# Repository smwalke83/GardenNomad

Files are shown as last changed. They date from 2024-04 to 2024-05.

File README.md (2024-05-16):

The Garden Nomad is a garden monitoring system that monitors local environmental data - as well as having a deployable digital PH meter - and sends it to the cloud. This project was done for the CNM Ingenuity IoT Bootcamp. It is the capstone project. In this repository you will find all of the documentation for this project. You will see six different folders here:

Code - This contains all of the coding I did for this project. There are several test code files, as well as the final code.

Proposal - Contains the original project proposal.

Drawings, Notes, and Flowcharts - Contains everything that was in my notebook at the end of this project. Conceptual drawings, measurements, notes, flowcharts, etc.

Fritzing - Contains the wiring schematic and breadboard fritzing files.

Garden Nomad PCB - Contains the files for the Printed Curcuit Board design.

Solidworks and Other Design - Contains all the Solidworks files for the 3D printed housing design, as well as an Adobe Illustrator file for the acrylic piece that was cut on the laser cutter.

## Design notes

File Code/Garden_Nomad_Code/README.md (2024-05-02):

# Garden_Nomad_Code

This firmware project was created using [Particle Developer Tools](https://www.particle.io/developer-tools/) and is compatible with all [Particle Devices](https://www.particle.io/devices/).

Feel free to replace this README.md file with your own content, or keep it for reference.

## Table of Contents
- [Introduction](#introduction)
- [Prerequisites To Use This Template](#prerequisites-to-use-this-repository)
- [Getting Started](#getting-started)
- [Particle Firmware At A Glance](#particle-firmware-at-a-glance)
  - [Logging](#logging)
  - [Setup and Loop](#setup-and-loop)
  - [Delays and Timing](#delays-and-timing)
  - [Testing and Debugging](#testing-and-debugging)
  - [GitHub Actions (CI/CD)](#github-actions-cicd)
  - [OTA](#ota)
- [Support and Feedback](#support-and-feedback)
- [Version](#version)

## Introduction

For an in-depth understanding of this project template, please refer to our [documentation](https://docs.particle.io/firmware/best-practices/firmware-template/).

## Prerequisites To Use This Repository

To use this software/firmware on a device, you'll need:

- A [Particle Device](https://www.particle.io/devices/).
- Windows/Mac/Linux for building the software and flashing it to a device.
- [Particle Development Tools](https://docs.particle.io/getting-started/developer-tools/developer-tools/) installed and set up on your computer.
- Optionally, a nice cup of tea (and perhaps a biscuit).

## Getting Started

1. While not essential, we recommend running the [device setup process](https://setup.particle.io/) on your Particle device first. This ensures your device's firmware is up-to-date and you have a solid baseline to start from.

2. If you haven't already, open this project in Visual Studio Code (File -> Open Folder). Then [compile and flash](https://docs.particle.io/getting-started/developer-tools/workbench/#cloud-build-and-flash) your device. Ensure your device's USB port is connected to your computer.

3. Verify the device's operation by monitoring its logging output:
    - In Visual Studio Code with the Particle Plugin, open the [command palette](https://docs.particle.io/getting-started/developer-tools/workbench/#particle-commands) and choose "Particle: Serial Monitor".
    - Or, using the Particle CLI, execute:
    ```
    particle serial monitor --follow
    ```

4. Uncomment the code at the bottom of the cpp file in your src directory to publish to the Particle Cloud! Login to console.particle.io to view your devices events in real time.

5. Customize this project! For firmware details, see [Particle firmware](https://docs.particle.io/reference/device-os/api/introduction/getting-started/). For information on the project's directory structure, visit [this link](https://docs.particle.io/firmware/best-practices/firmware-template/#project-overview).

## Particle Firmware At A Glance

### Logging

The firmware includes a [logging library](https://docs.particle.io/reference/device-os/api/logging/logger-class/). You can display messages at different levels and filter them:

```
Log.trace("This is trace message");
Log.info("This is info message");
Log.warn("This is warn message");
Log.error("This is error message");
```

### Setup and Loop

Particle projects originate from the Wiring/Processing framework, which is based on C++. Typically, one-time setup functions are placed in `setup()`, and the main application runs from the `loop()` function.

For advanced scenarios, explore our [threading support](https://docs.particle.io/firmware/software-design/threading-explainer/).

### Delays and Timing

By default, the setup() and loop() functions are blocking whilst they run, meaning that if you put in a delay, your entire application will wait for that delay to finish before anything else can run. 

For techniques that allow you to run multiple tasks in parallel without creating threads, checkout the code example [here](https://docs.particle.io/firmware/best-practices/firmware-template/).

(Note: Although using `delay()` isn't recommended for best practices, it's acceptable for testing.)

### Testing and Debugging

For firmware testing and debugging guidance, check [this documentation](https://docs.particle.io/troubleshooting/guides/build-tools-troubleshooting/debugging-firmware-builds/).

### GitHub Actions (CI/CD)

This project provides a YAML file for GitHub, automating firmware compilation whenever changes are pushed. More details on [Particle GitHub Actions](https://docs.particle.io/firmware/best-practices/github-actions/) are available.

### OTA

To learn how to utilize Particle's OTA service for device updates, consult [this documentation](https://docs.particle.io/getting-started/cloud/ota-updates/).

Test OTA with the 'Particle: Cloud Flash' command in Visual Studio Code or the CLI command 'particle flash'!

This firmware supports binary assets in OTA packages, allowing the inclusion of audio, images, configurations, and external microcontroller firmware. More details are [here](https://docs.particle.io/reference/device-os/api/asset-ota/asset-ota/).

## Support and Feedback

For support or feedback on this template or any Particle products, please join our [community](https://community.particle.io)!

## Version

Template version 1.0.2

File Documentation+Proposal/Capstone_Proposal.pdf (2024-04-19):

Internet of Things and Rapid Prototyping Bootcamp – Capstone Project Proposal

Rev 1.0

Project Name: TBD
Student Name: Scott Walker | Capstone Date: 5/17/2024
Project Motivation and Overview:
As myself and many around me have developed an interest in gardening, I have found that it can be tough to keep up with everything required to grow healthy plants and produce. It’s not quite as simple as Water + Sun = Plant. I thought it would be good to have a device that collects and tracks as many data points as possible from the garden or greenhouse and publish the data locally and to the cloud to be viewed and parsed.
Minimum Features:
- Local environmental and soil conditions
- PH sensor (manual deployment)
- Light levels
- Publish data to Node Red (WiFi for prototype, LoRa or BLE to another device for implementation)
- Solar/battery power
Desired Features:
- Automated reminders (water, fertilize, etc)
- Some sort of control from Node Red dashboard
- Keypad input to change reminder schedule, input optional data (manually collected nutrient data) Stretch Goal Features:
- Automated watering
- Automated soil PH testing (see Concerns and Considerations)
- Some form of nutrient monitoring (see Concerns and Considerations)
- Runoff collection for further analysis
Anticipated Components:
- Much of what we used on other projects (BME, OLED, perhaps dust and AQ sensors)
- PH Sensor (water PH sensor for manual deployment, or soil PH sensor if practical)
- Solar components
- Ambient Light Detection (photosensor? Something else?)
Concerns and Considerations (Project Risks and Potential Mitigations)
- I initially wanted to be able to monitor PH and nutrient levels from sensors in the soil. From my research, that appears to be pretty much impossible for nutrients (there are products that claim to do it, but the consensus seems to be that those are scams).
- There are also products that claim to test soil PH and can be inserted into the soil. Their accuracy and consistency (particularly while remaining in the soil) are in question. Given enough time, I would love to test one of these products and attempt to implement it, but this may not be the time.
- It seems I won’t be able to use a sensor for nutrient levels in soil, so I may include some form of runoff collection and test strips for that water to keep track of nutrient levels. If I do this (and time permitting), I may create a way to input these values into the device to be sent to the cloud.
- If I ultimately decide I need to use a water PH sensor, it can be manually deployed on both runoff water and water that has not entered the soil yet. You can also more directly check soil PH with a soil/water mixture. If I end up with a ton of extra time, I may attempt to automate some form of this soil/water mixing/testing process.
- Automated watering/feeding is an option, but may be difficult to implement on a large enough scale for most gardens.
Other Information:

Internet of Things and Rapid Prototyping Bootcamp – Capstone Project Proposal

Rev 1.0

Project Implementation Timeline:
Tasks | 12-APR | 19-APR | 26-APR | 3-May | 10-May | 17-May
Project Plan | X
Drawings | | X
Flowcharts | | X
Fritzing | | | X
Designs | | | X
Coding/Testing | | | | X
Fabrication | | | | | X
Finalizing | | | | | | X
Documentation | | | | | | X
Create Presentation | | | | | | X
Capstone Presentation | | | | | | X

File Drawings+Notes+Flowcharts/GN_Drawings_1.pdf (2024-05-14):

I\h ,5

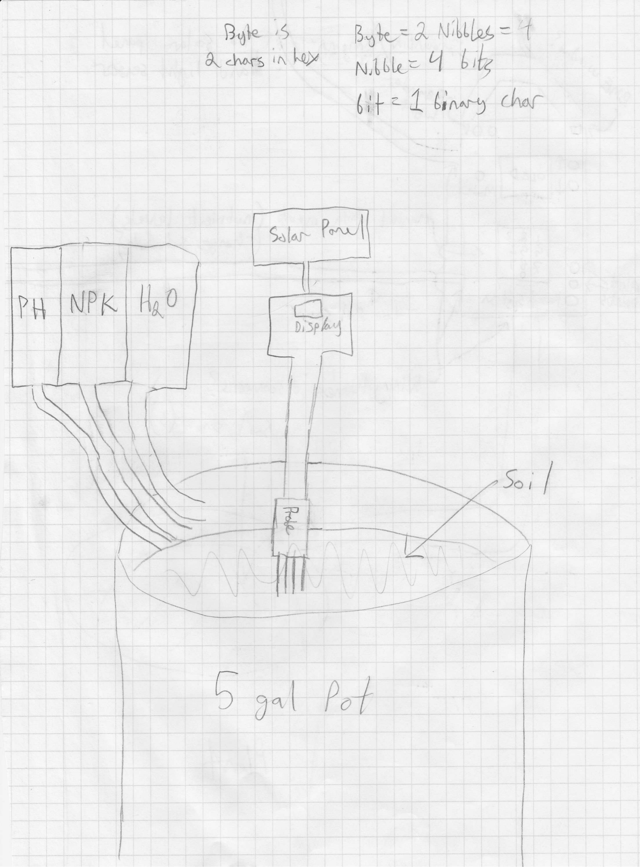
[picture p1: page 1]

{.ha.rs i" t"o}

8"6|u=A rui[tfo4= I
fu*i,t ' '/ L'b
6i,l' ( AJn*g rl'rxr

# 5 fr^l P,l

golor P*t I

\
---\ -\\--
NPK | T

## I 'Sr', {

l- ,--J l,l 't4
l,i

### _J r-

t\ ,'5"; f \1

,/\

# /eL V

### l]tT

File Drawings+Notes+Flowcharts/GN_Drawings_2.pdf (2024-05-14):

# ffis

## n"^*[ klu

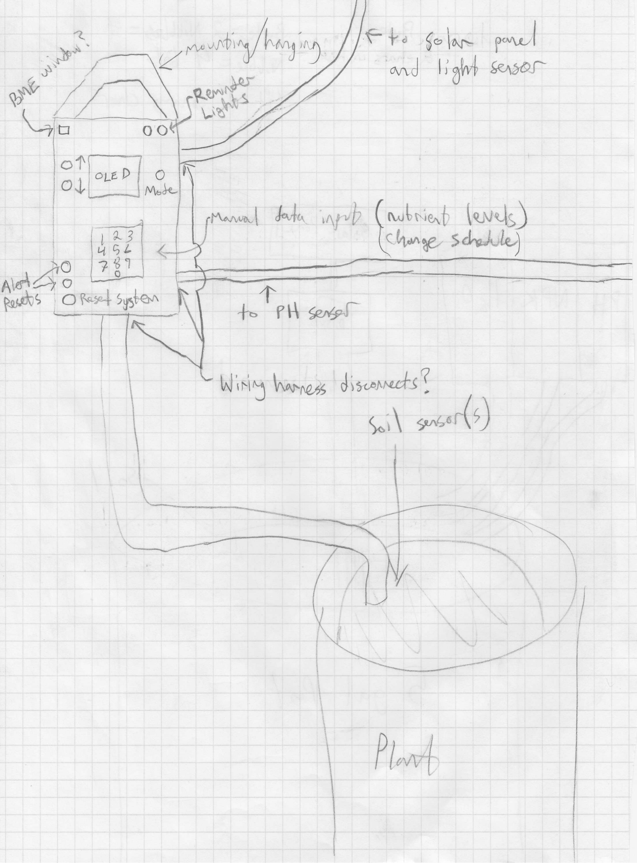
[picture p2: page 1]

### F {,, f. in1= yrrl '*rJ lid& k4rer

## +.fr A kgr

Jr**n*is7.

### Ii\ *..r":(')

i

I

1

i

I

It,l

# Ptd

?
- ,b* $'

SN?
\* | ooq

'h ⁽ u,[n;e^f tuv{)
(.h*p sddJ*,)

## nrd43 @ f

gqifrg O [kt.+ 9,'f+t I

' [^lir.i3 hnFnarg

/

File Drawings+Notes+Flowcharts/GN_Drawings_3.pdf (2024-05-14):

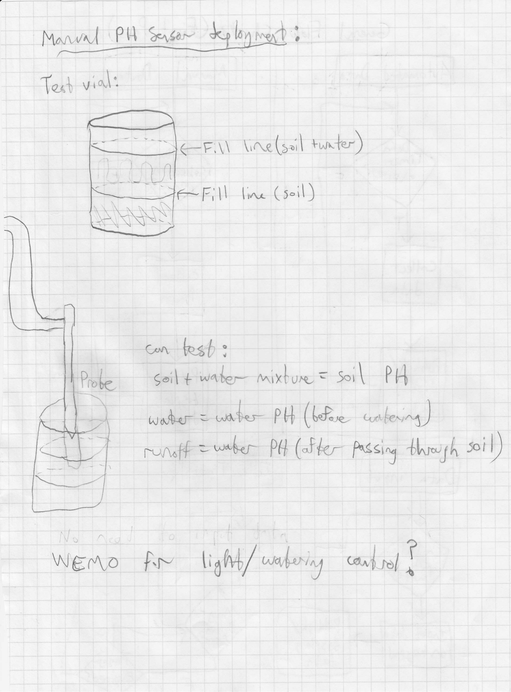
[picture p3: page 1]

ltlrw,rn {Tt{ !*ags" J(fb ;

I | r | r i.
f a,, t 1,f r crvl
'

(-tr.\\

### r-F;II

\r\( (r",\ u**-")

### t,,r^ (l.il)

G^^ hs/ :

## g.l\ t ,^{"-

^ixlunq- = 5";\ PF{
w,,$*r = *{*- Pf+ (t#,* ,,,,[".,1J r.r^*f{ = -of,.r Pfi Gf kt F.stiY {t'*;dt 'i,
Wfgr\o f.n, t;,6fi+*f | *"d dl *qb,ri^J

il
)\r:"
/!{5[. '
/'--{J- I
Er

) -) -

t..ti\ -" I
\]-2

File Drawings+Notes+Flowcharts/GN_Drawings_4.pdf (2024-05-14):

## B *"J &o-;-J ^ to ^^ tti ck- t

## l'^^Yu idf

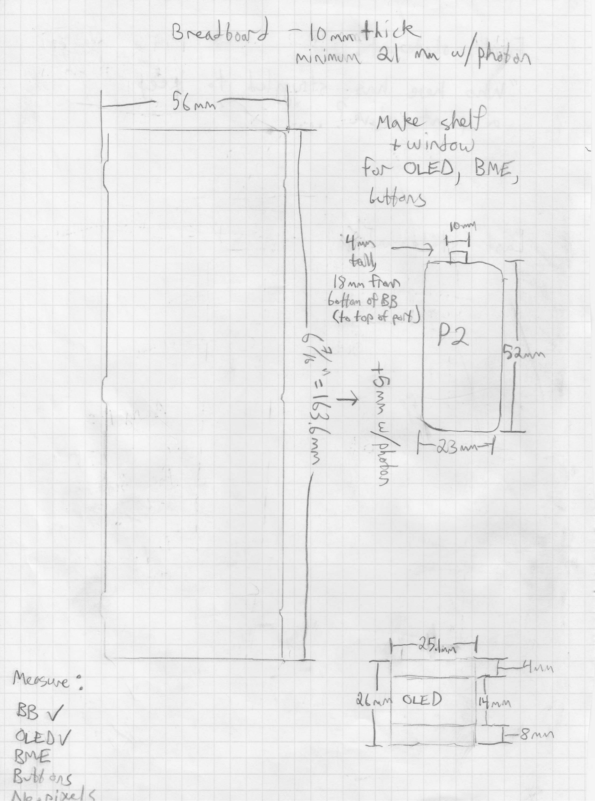
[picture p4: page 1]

{'ni,\i*,r .,r S"t ,'\n. *// pfui o,i

Cz JSntr

l,q,,"l <
{q,U
*^ +I.c,f.

### *ofBE

,*ql .f f

't{o
{q
l8^^
L"lf^
(*" *.

I
t,

+
$t -+2

5
C
---p\
F*
a.
C)

## + ur inlo*

## ["r oLFD] Bn4

l^,fFnS

PZ

I.-a;+

Na

E

'Fr | I

l5a*^

I

f\Na.\

1\

### a\ U\) b\

3
3

f%tgw<, ",
8B/

# qgs/

Bl4€

### B-*f *.as

## Ab*nirai{

JI

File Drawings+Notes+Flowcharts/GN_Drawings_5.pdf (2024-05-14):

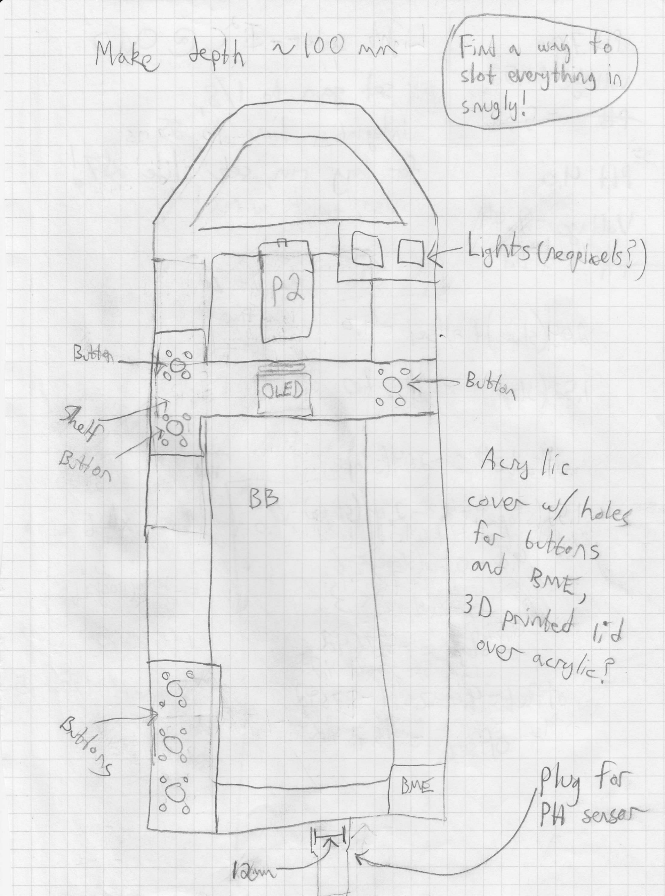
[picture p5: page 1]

lL"ke hp+h "' f oo \//\

Lgh#s Uuryiw.bf)

g'#rr

A'y [;,

q/,{

.4
-5 | Pbtk
i | Ph'su&r

F;n,i dr uiarl f oglal *tf^J+er"j in
sqill

q#

ff*t '/

b' 9()

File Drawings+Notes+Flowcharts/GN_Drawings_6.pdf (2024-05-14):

t"(-

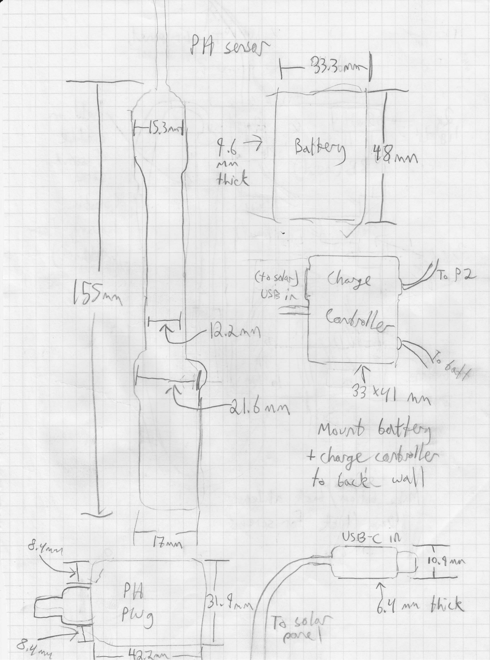
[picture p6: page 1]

PN

t,l, d ,v\^\

3? \71 aa

UsB-c r{r :T_

1 lO"{,rrrr
JI

PL4
rkj 3
I. $r,nt | I", ^^ [rr;.(

t4rv\
+tu'.(.

r' IIu sdi i e(},"\s,

],'

[5r"*

0i

tilr11.
-D,- I
t | - 3,fr- | /7^^,r | J

t

,nd

n^,4
]

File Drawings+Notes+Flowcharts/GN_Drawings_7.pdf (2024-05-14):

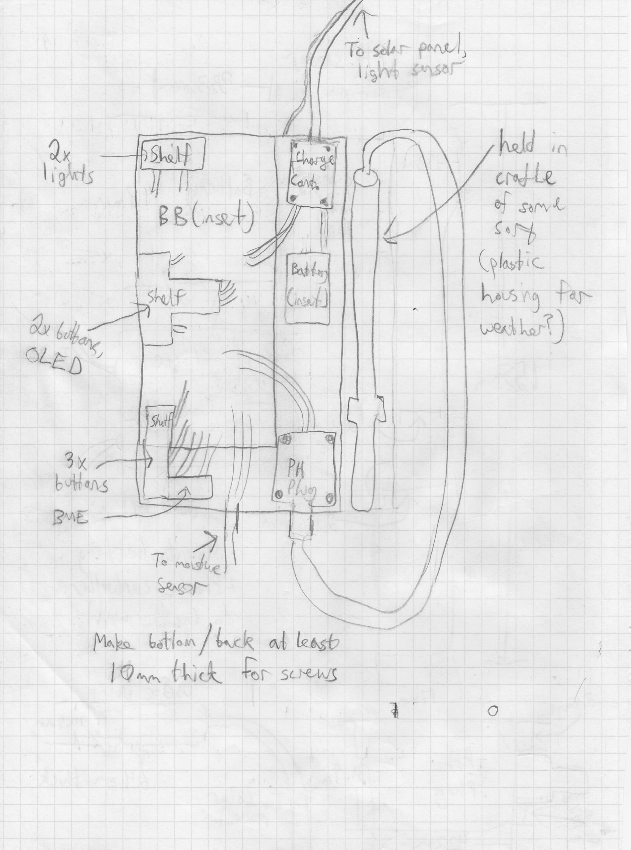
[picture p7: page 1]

"J 50n n- r'Y

(11^'{;c
l^rous r1 lr*
urer.,l t -r! *w

1x,

b *t{ons

### Bur

)
1 *"'Ju.t

# k"pf

l€^^ ft^;.[- f. scr-e,h8

Qx
lr'rf#s

t

# ,lf v r-'

l!
I

a

nS.
4

o

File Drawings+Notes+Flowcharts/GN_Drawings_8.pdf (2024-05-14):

I
1,

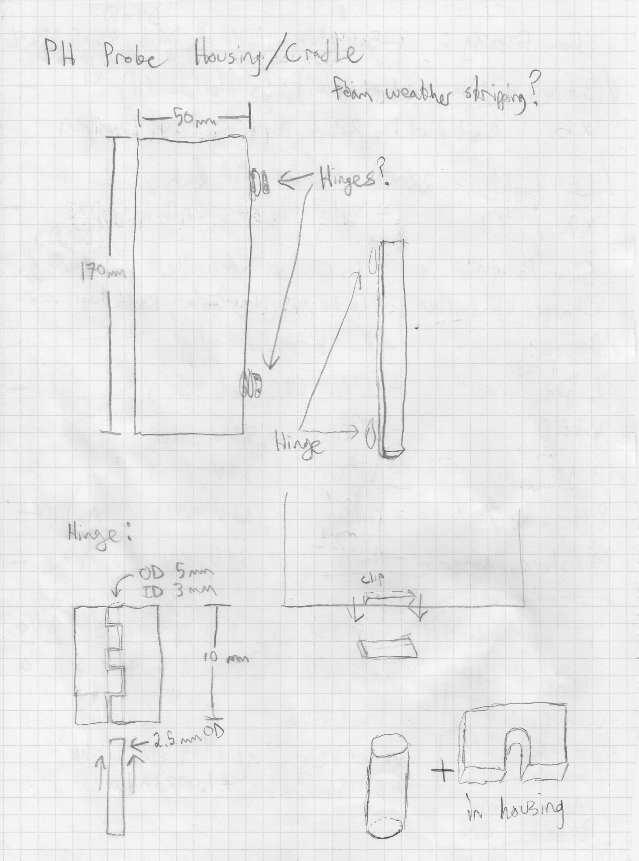
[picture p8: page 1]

P [ ?*il* [iu,r,y /c'*J i e-,

[-$h**+ tb'^ wn'"ht'fi' *{n;ff'y?

I
l?tr,^ '

illr.,s. a :
o-
-- OD 5 '**'- $ TD 3 *.nl

## **- -a\ \__J

### \^ [r^.e't

5n^^uD

I
t
I
I

H,wr?.

## vt I

## His

# Il0 ra.^

U | ffi

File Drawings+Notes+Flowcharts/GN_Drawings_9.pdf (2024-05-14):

## Fll^

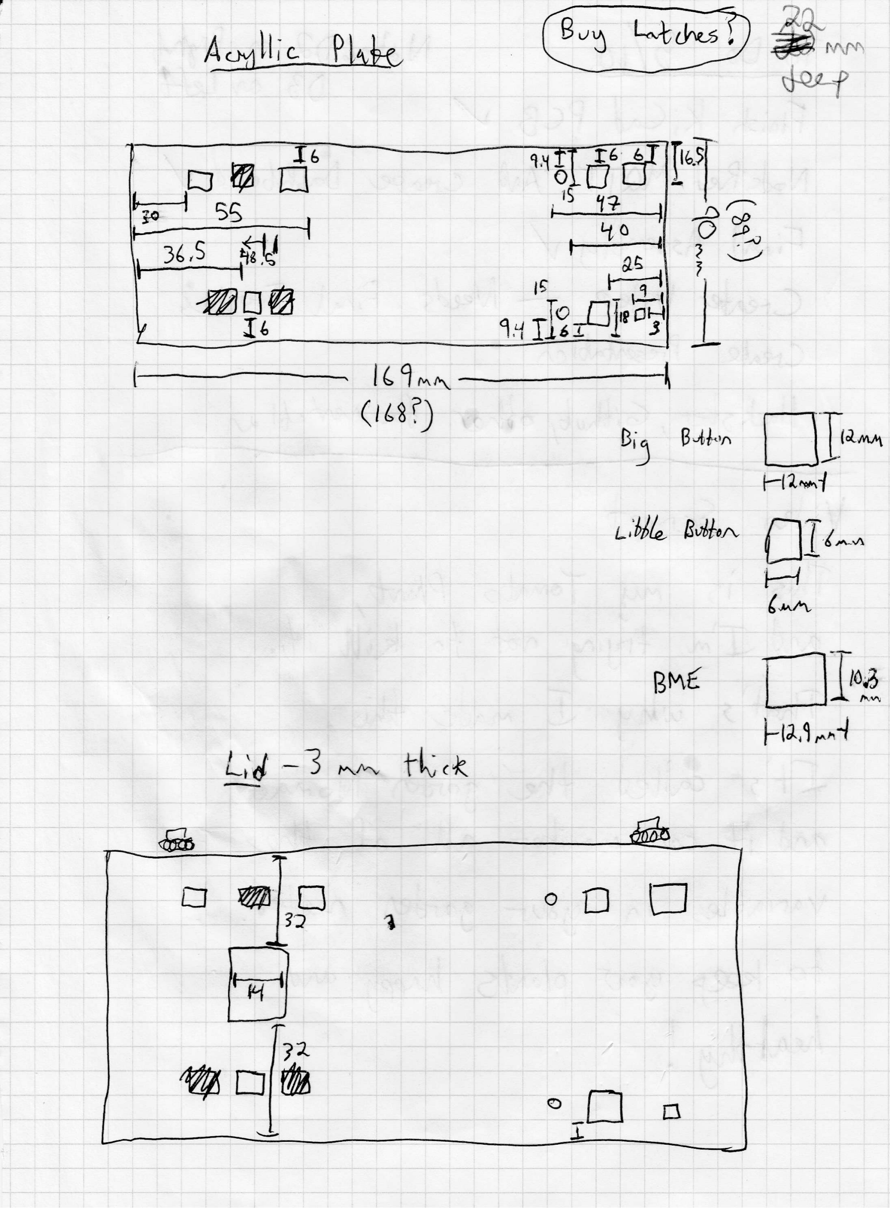
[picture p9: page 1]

l( 9 ^^. (re8i)

U -3 ^\^^\. l[",f

6'.%1-:

t_

i-re,l.^'{

:_.1_?^J,
1,, O 'l 'll
4t I
o(> H

## 'trl'4

O,) B,tJ",'

## itlL Bdhn

# Bh( L]I,E

II'*

| f(1" -l fllr^- l--t- ?1 Gn

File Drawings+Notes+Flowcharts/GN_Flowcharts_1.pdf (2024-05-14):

# Ft,* @r, (F;,r| P*J

F

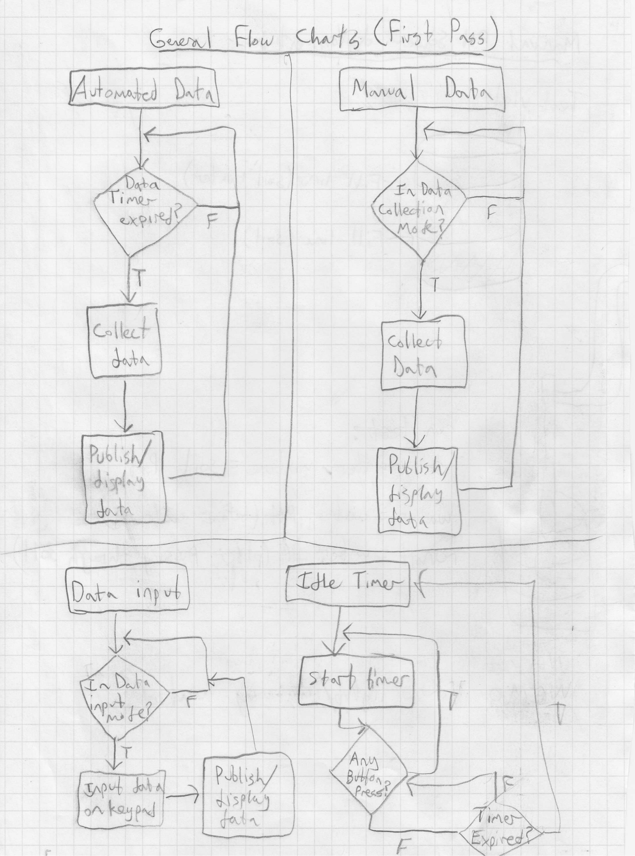
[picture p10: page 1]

yl,^dJ D^,{-n'

r rv\fu:.
-*t,sJF

Puili;sU
4l#-r

&.'i',

P"bt,sV

### Jr:r{4

#o{ "-

### M-,'a \ D*t^"

C"tfn i'"^

c"It""'l

Pr&|;: h
[.,:N"y
J"t r.

## fo^u\

$*

$AP*t ds'I Al-J
"^ koi1 f*J I t

I
l\

,ltq{
&i

# lrc'*-

{,;l
T

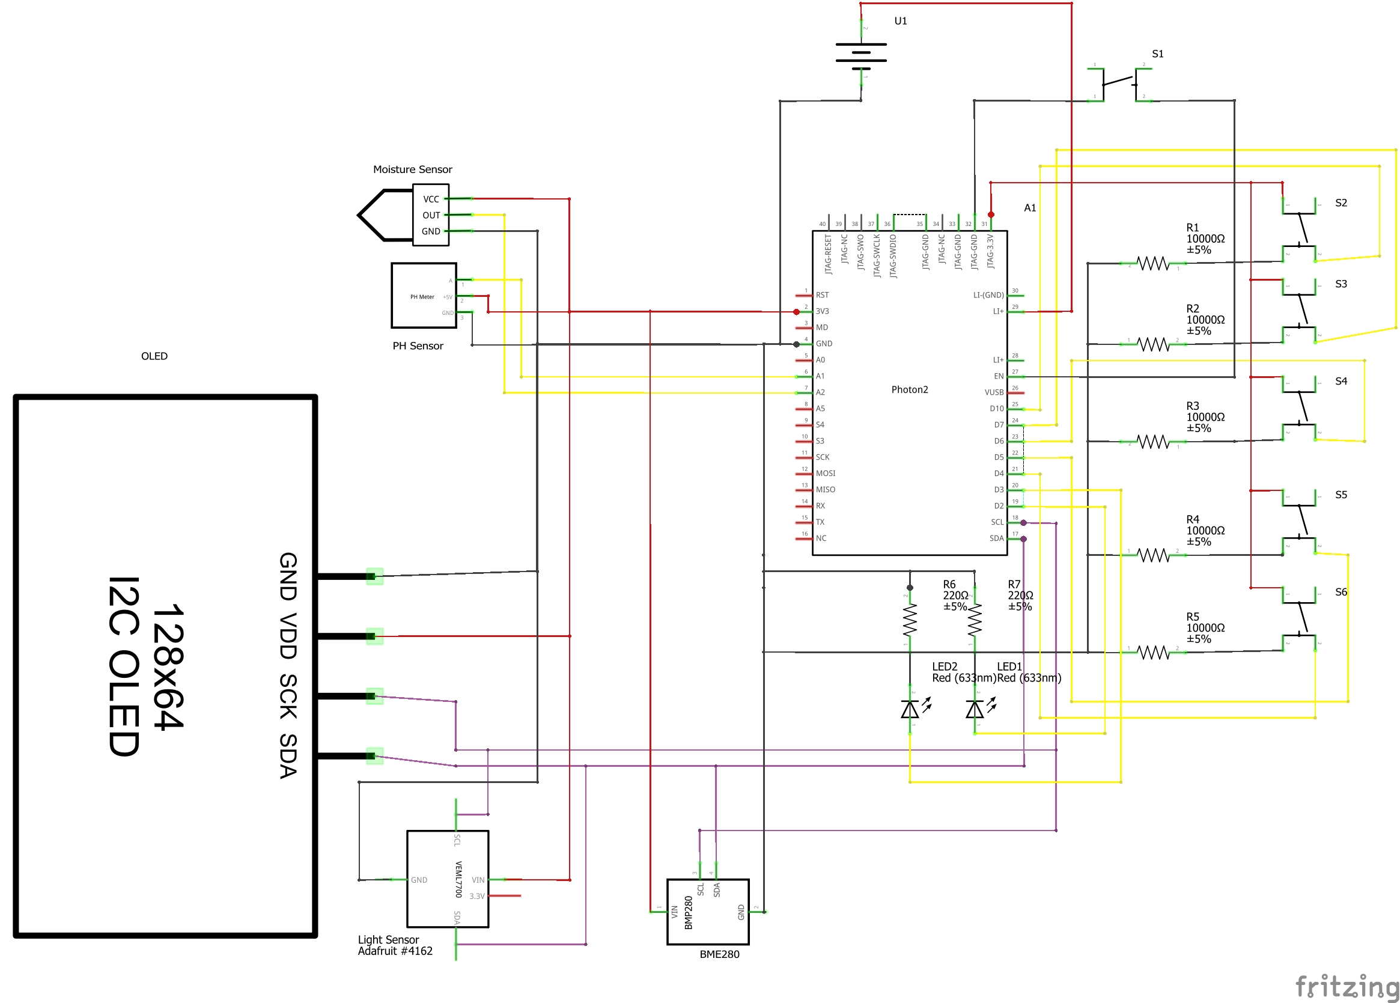
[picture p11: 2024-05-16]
Fritzing/Garden_Nomad_Fritzing_schem.jpg

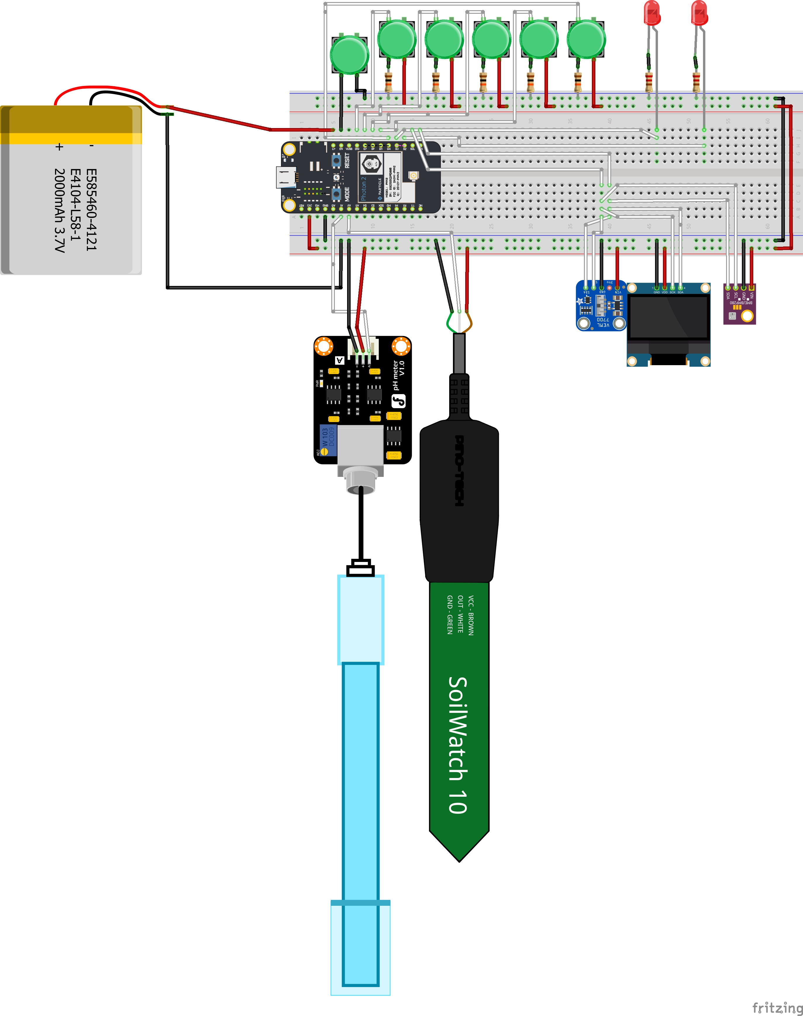
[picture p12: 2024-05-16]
Fritzing/Garden_Nomad_Fritzing_bb.jpg

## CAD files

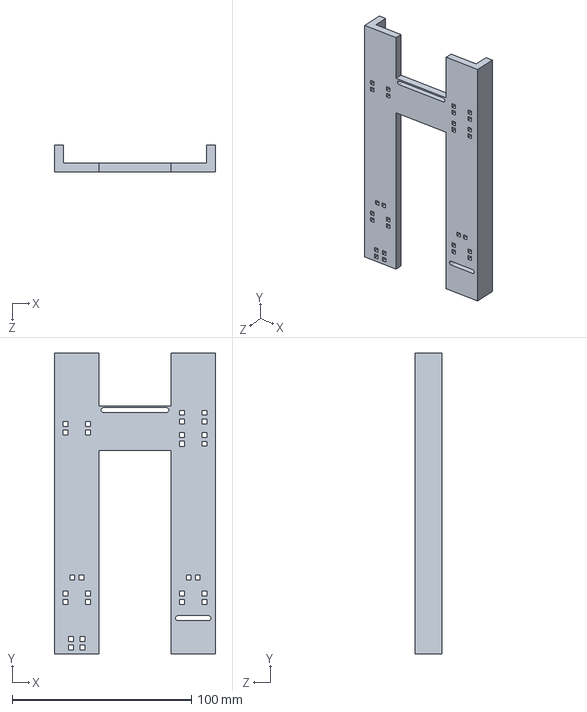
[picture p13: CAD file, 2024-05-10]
Solidworks+Other Design/Main_Body_Shelving.SLDPRT
90.0 x 168.0 x 15.0 mm

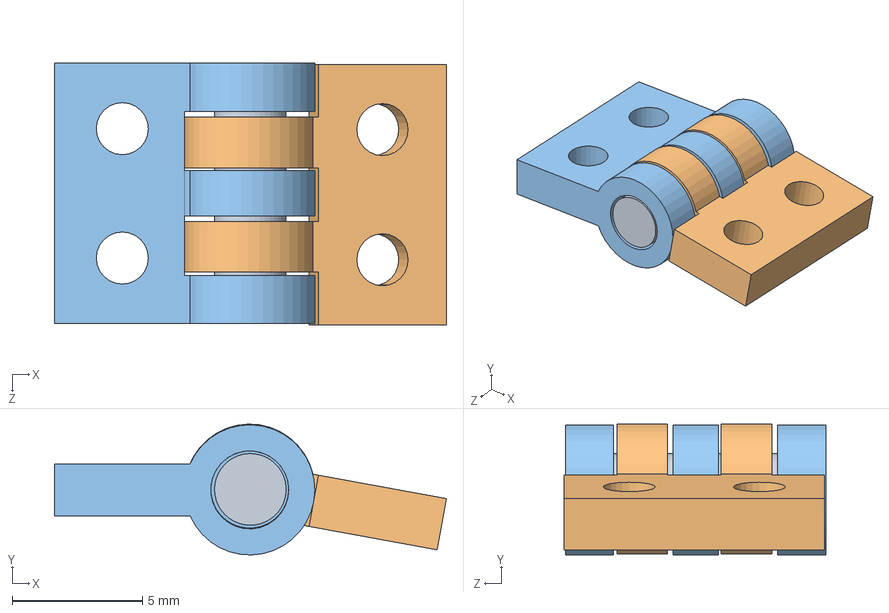
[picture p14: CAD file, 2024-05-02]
Solidworks+Other Design/Hinge_Assembly.SLDASM
15.1 x 5.03 x 10.1 mm
Hinge_Side_1
Hinge_Side_2
Hinge_Pin

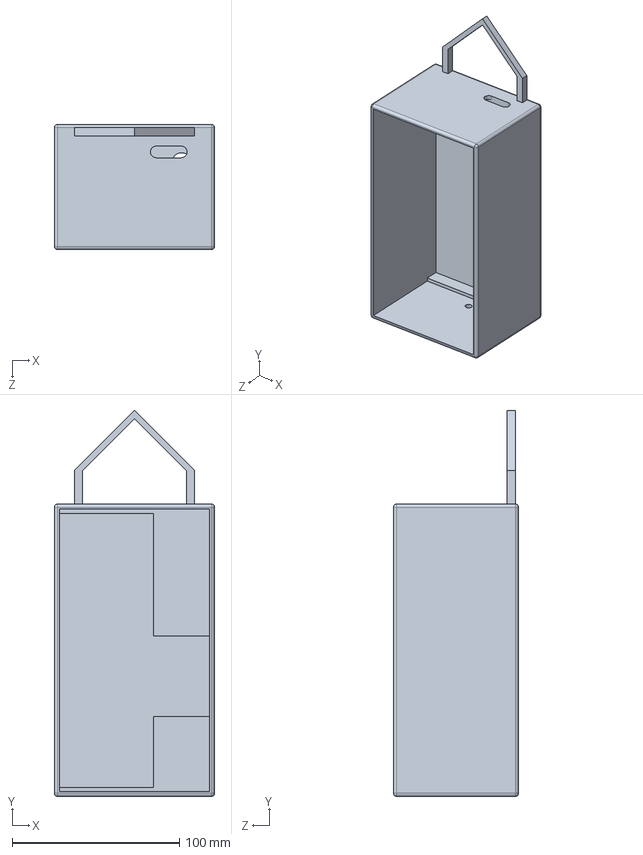
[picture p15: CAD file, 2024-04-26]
Solidworks+Other Design/Main_Body_Case.SLDPRT
96.0 x 231.0 x 75.0 mm

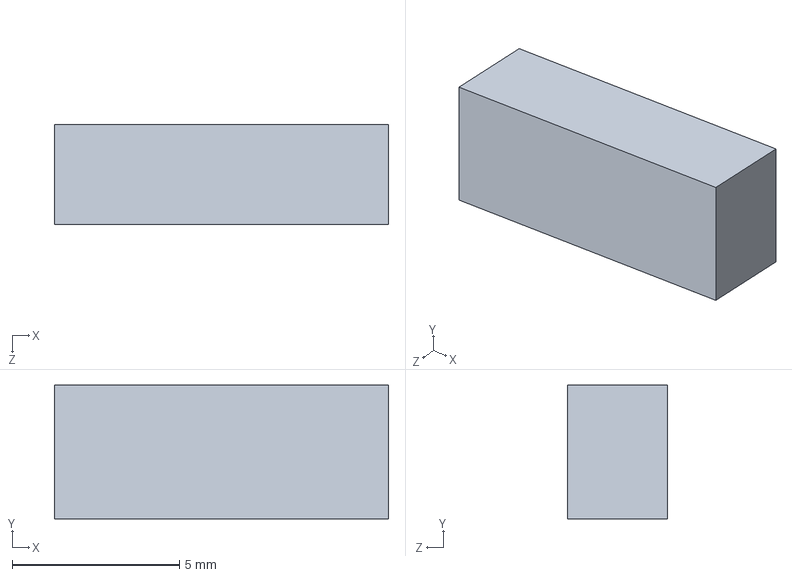
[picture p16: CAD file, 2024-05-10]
Solidworks+Other Design/Shelf_Support.SLDPRT
10.0 x 4.00 x 3.00 mm

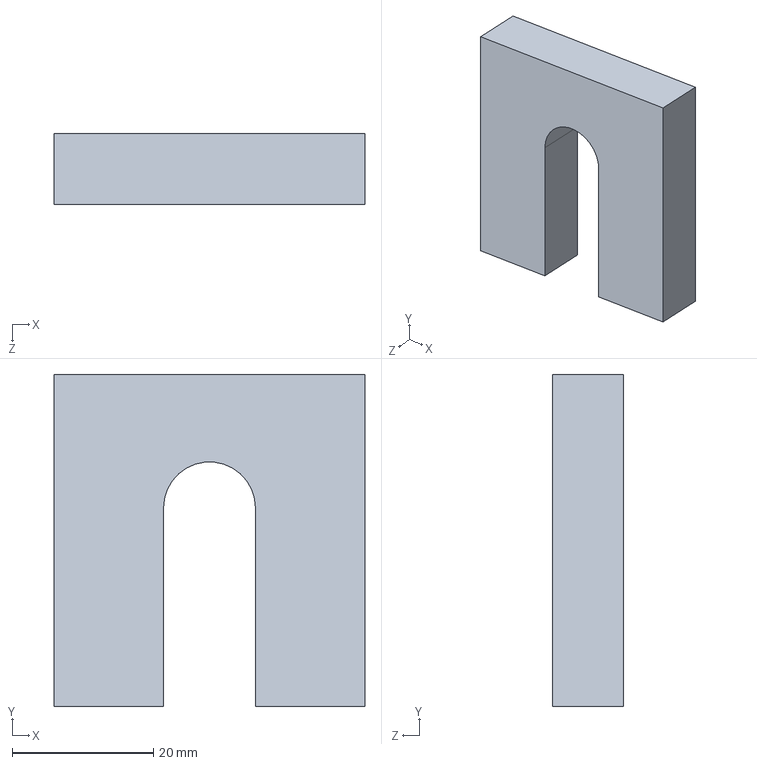
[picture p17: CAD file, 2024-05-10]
Solidworks+Other Design/PH_Probe_Cradle_2.SLDPRT
44.0 x 47.0 x 10.0 mm

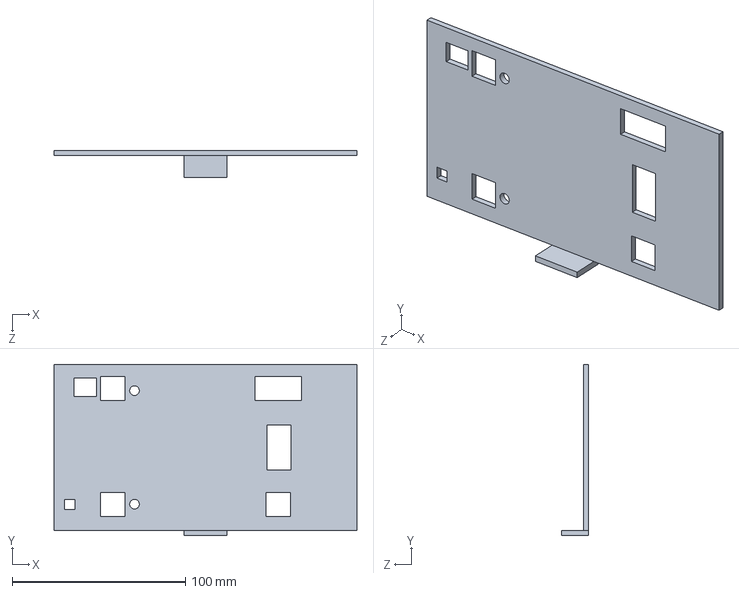
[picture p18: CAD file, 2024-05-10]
Solidworks+Other Design/Front_Door.SLDPRT
175.0 x 99.0 x 15.8 mm

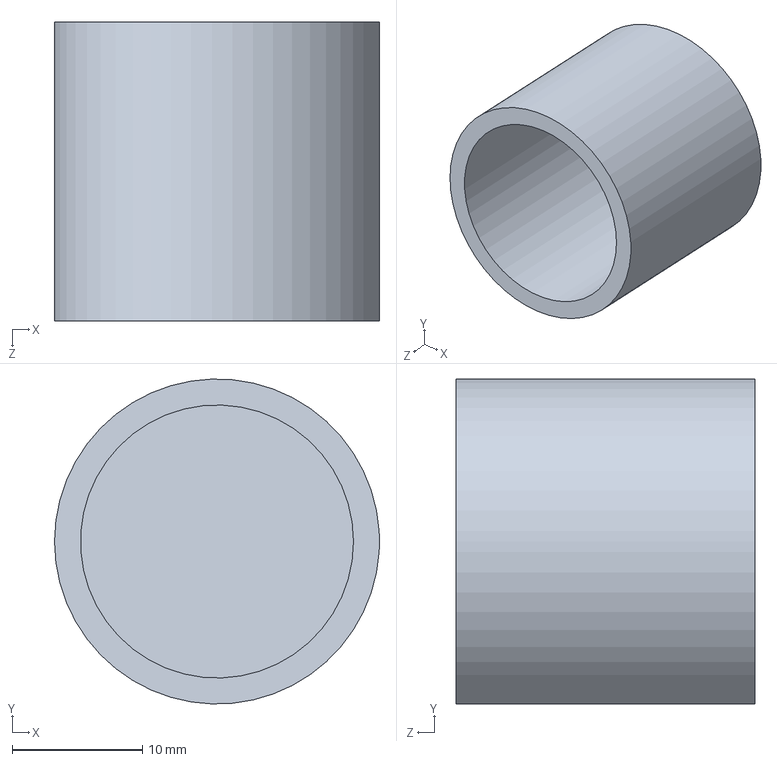
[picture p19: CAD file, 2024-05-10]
Solidworks+Other Design/PH_Probe_Cradle_1.SLDPRT
25.0 x 25.0 x 23.0 mm

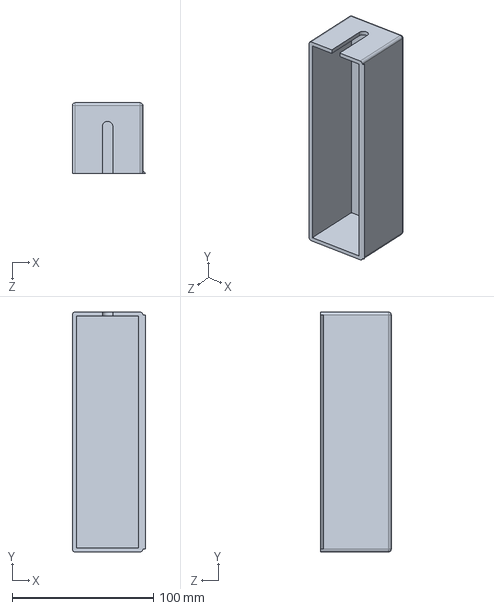
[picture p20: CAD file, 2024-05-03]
Solidworks+Other Design/PH_Probe_Housing.SLDPRT
52.0 x 170.0 x 50.0 mm

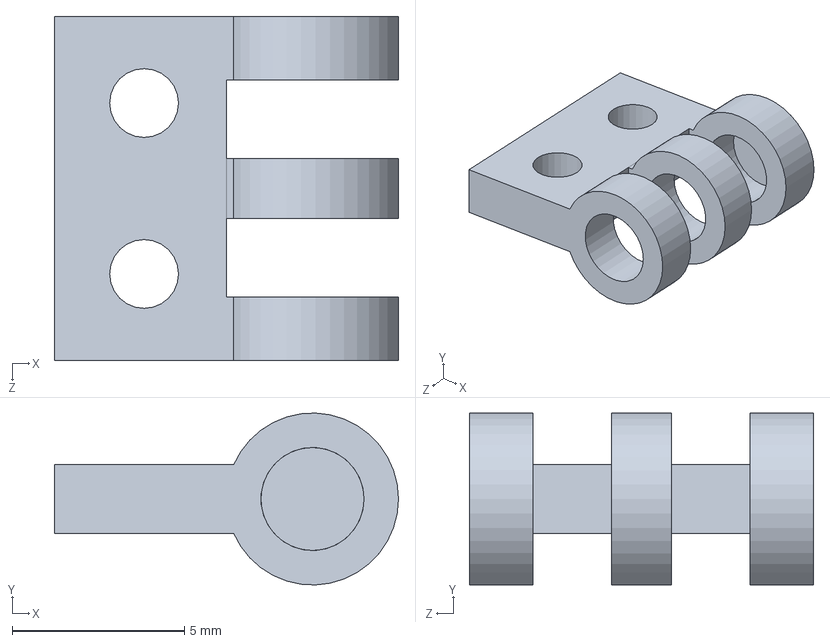
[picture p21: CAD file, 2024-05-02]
Solidworks+Other Design/Hinge_Side_1.SLDPRT
10.0 x 5.00 x 10.0 mm

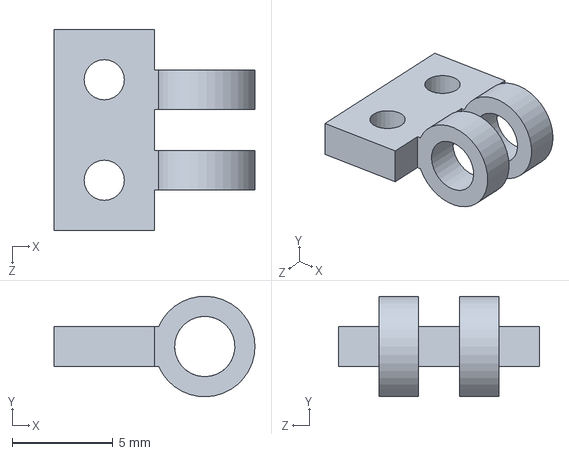
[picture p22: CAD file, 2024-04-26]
Solidworks+Other Design/Hinge_Side_2.SLDPRT
10.0 x 5.00 x 10.0 mm

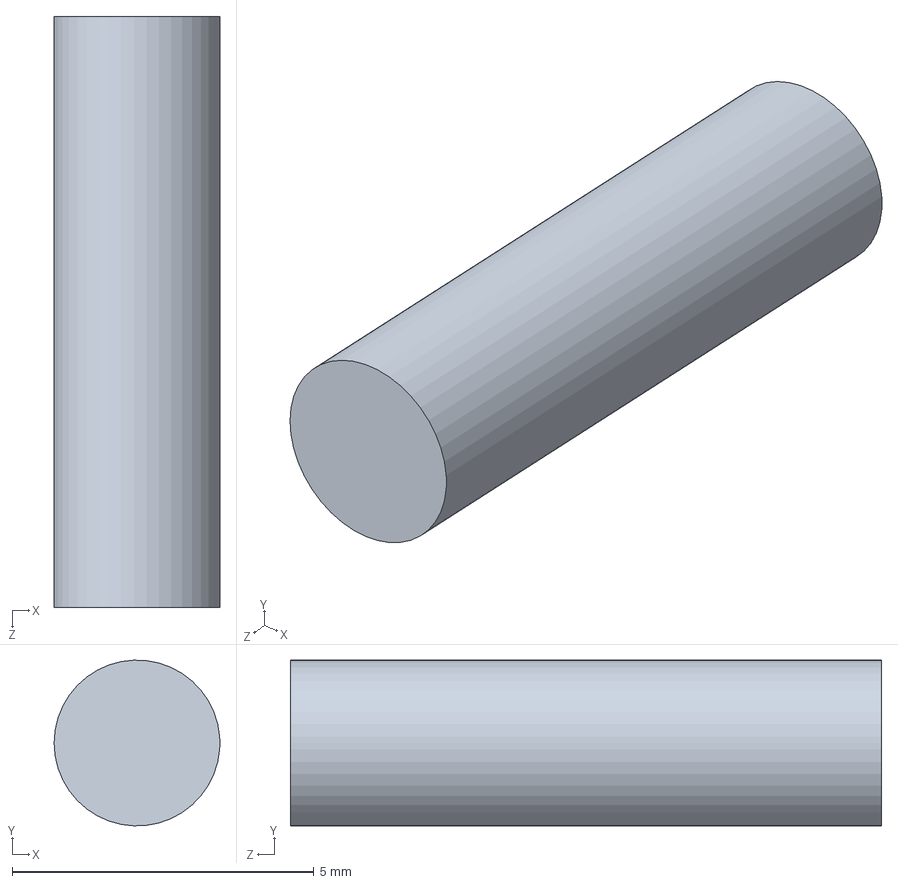
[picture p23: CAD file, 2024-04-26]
Solidworks+Other Design/Hinge_Pin.SLDPRT
2.75 x 2.75 x 9.80 mm

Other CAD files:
Solidworks+Other Design/Front_Door.STL
Solidworks+Other Design/Hinge_Assembly.STL
Solidworks+Other Design/Hinge_Pin.STL
Solidworks+Other Design/Hinge_Side_1.STL
Solidworks+Other Design/Hinge_Side_2.STL
Solidworks+Other Design/Main_Body_Case.STL
Solidworks+Other Design/Main_Body_Shelving.STL
Solidworks+Other Design/PH_Probe_Cradle_1.STL
Solidworks+Other Design/PH_Probe_Cradle_2.STL
Solidworks+Other Design/PH_Probe_Housing.STL
Solidworks+Other Design/Shelf_Support.STL

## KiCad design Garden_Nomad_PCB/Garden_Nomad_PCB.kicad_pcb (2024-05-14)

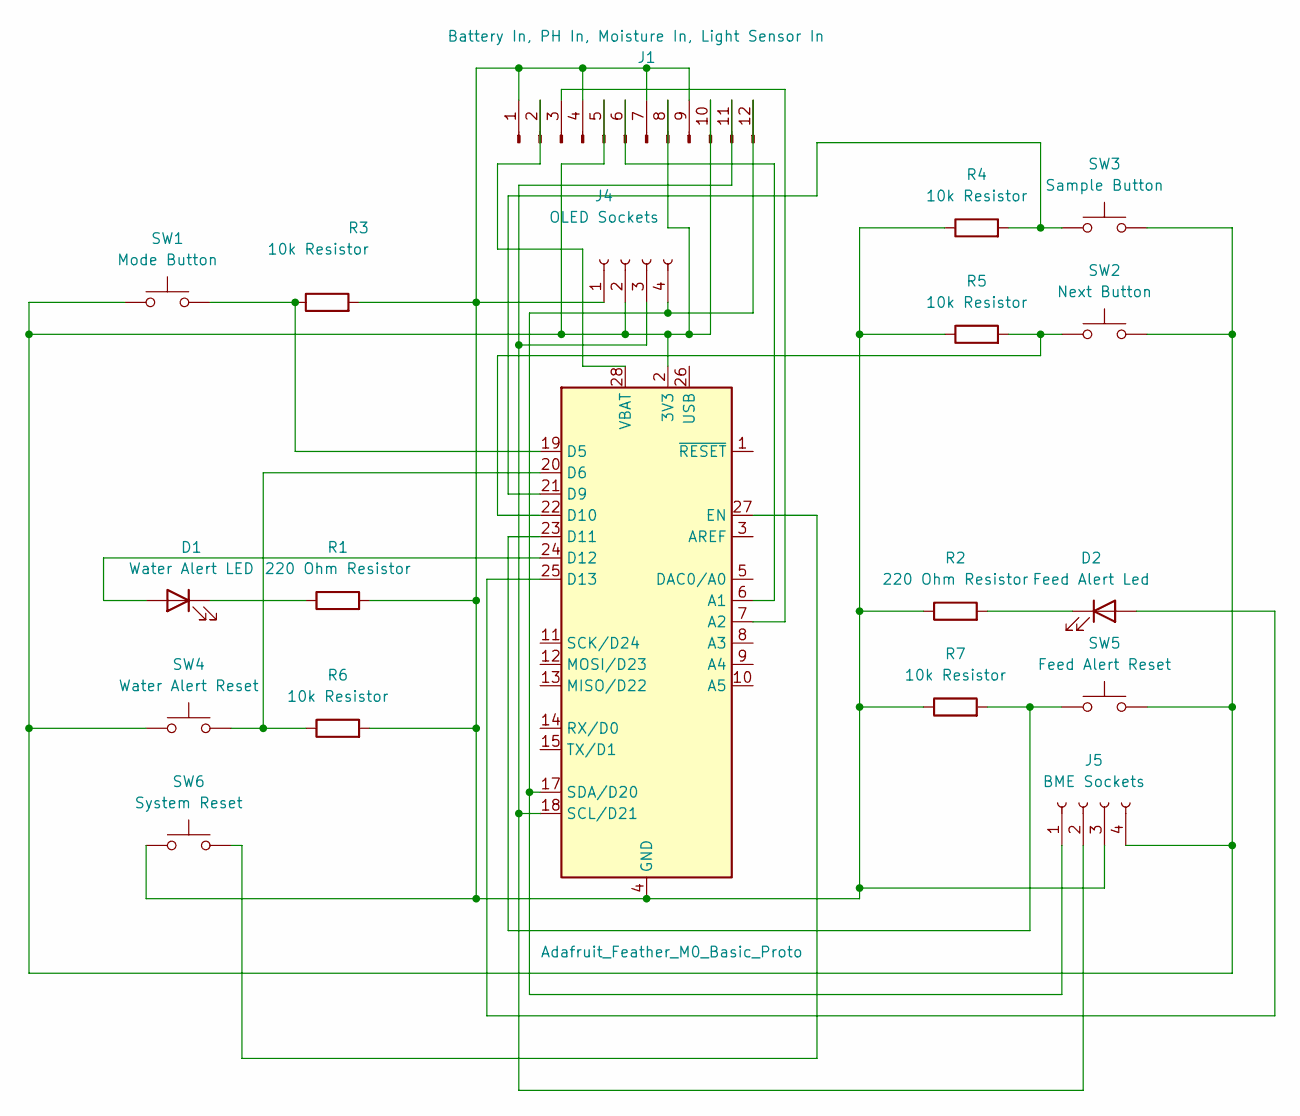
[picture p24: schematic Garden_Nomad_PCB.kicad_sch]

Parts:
A1: Adafruit_Feather_M0_Basic_Proto; Adafruit_Feather
D1: Water Alert LED; LED_D3.0mm
D2: Feed Alert Led; LED_D3.0mm
J1: Battery In, PH In, Moisture In, Light Sensor In; PinHeader_1x12_P2.54mm_Horizontal
J4: OLED Sockets; PinSocket_1x04_P2.54mm_Vertical
J5: BME Sockets; PinSocket_1x04_P2.54mm_Vertical
R1, R2: 220 Ohm Resistor; R_Axial_DIN0204_L3.6mm_D1.6mm_P5.08mm_Horizontal
R3, R4, R5, R6, R7: 10k Resistor; R_Axial_DIN0204_L3.6mm_D1.6mm_P5.08mm_Horizontal
SW1: Mode Button; SW_PUSH_6mm_H5mm
SW2: Next Button; SW_PUSH_6mm_H5mm
SW3: Sample Button; SW_PUSH_6mm_H5mm
SW4: Water Alert Reset; SW_PUSH_6mm_H5mm
SW5: Feed Alert Reset; SW_PUSH_6mm_H5mm
SW6: System Reset; SW_PUSH_6mm_H5mm

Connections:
unnamed: A1.2 (3V3), J1.5, J1.8, J1.10, J4.2, J5.4, SW1.1, SW2.2, SW3.2, SW4.1, SW5.2
unnamed: A1.6 (A1), J1.6
unnamed: A1.7 (A2), J1.3
unnamed: A1.19 (D5), R3.1, SW1.2
unnamed: A1.20 (D6), R6.1, SW4.2
unnamed: A1.21 (D9), R4.2, SW3.1
unnamed: A1.22 (D10), R5.2, SW2.1
unnamed: A1.23 (D11), R7.2, SW5.1
unnamed: A1.24 (D12), D1.2 (A)
unnamed: A1.25 (D13), D2.2 (A)
unnamed: A1.27 (EN), SW6.2
unnamed: A1.18 (SCL/D21), J1.11, J4.3, J5.2
unnamed: A1.17 (SDA/D20), J1.12, J4.4, J5.1
unnamed: A1.28 (VBAT), J1.2
unnamed: D1.1 (K), R1.1
unnamed: D2.1 (K), R2.2
unnamed: A1.4 (GND), A1.16 (GND), J1.1, J1.4, J1.7, J1.9, J4.1, J5.3, R1.2, R2.1, R3.2, R4.1, R5.1, R6.2, R7.1, SW6.1

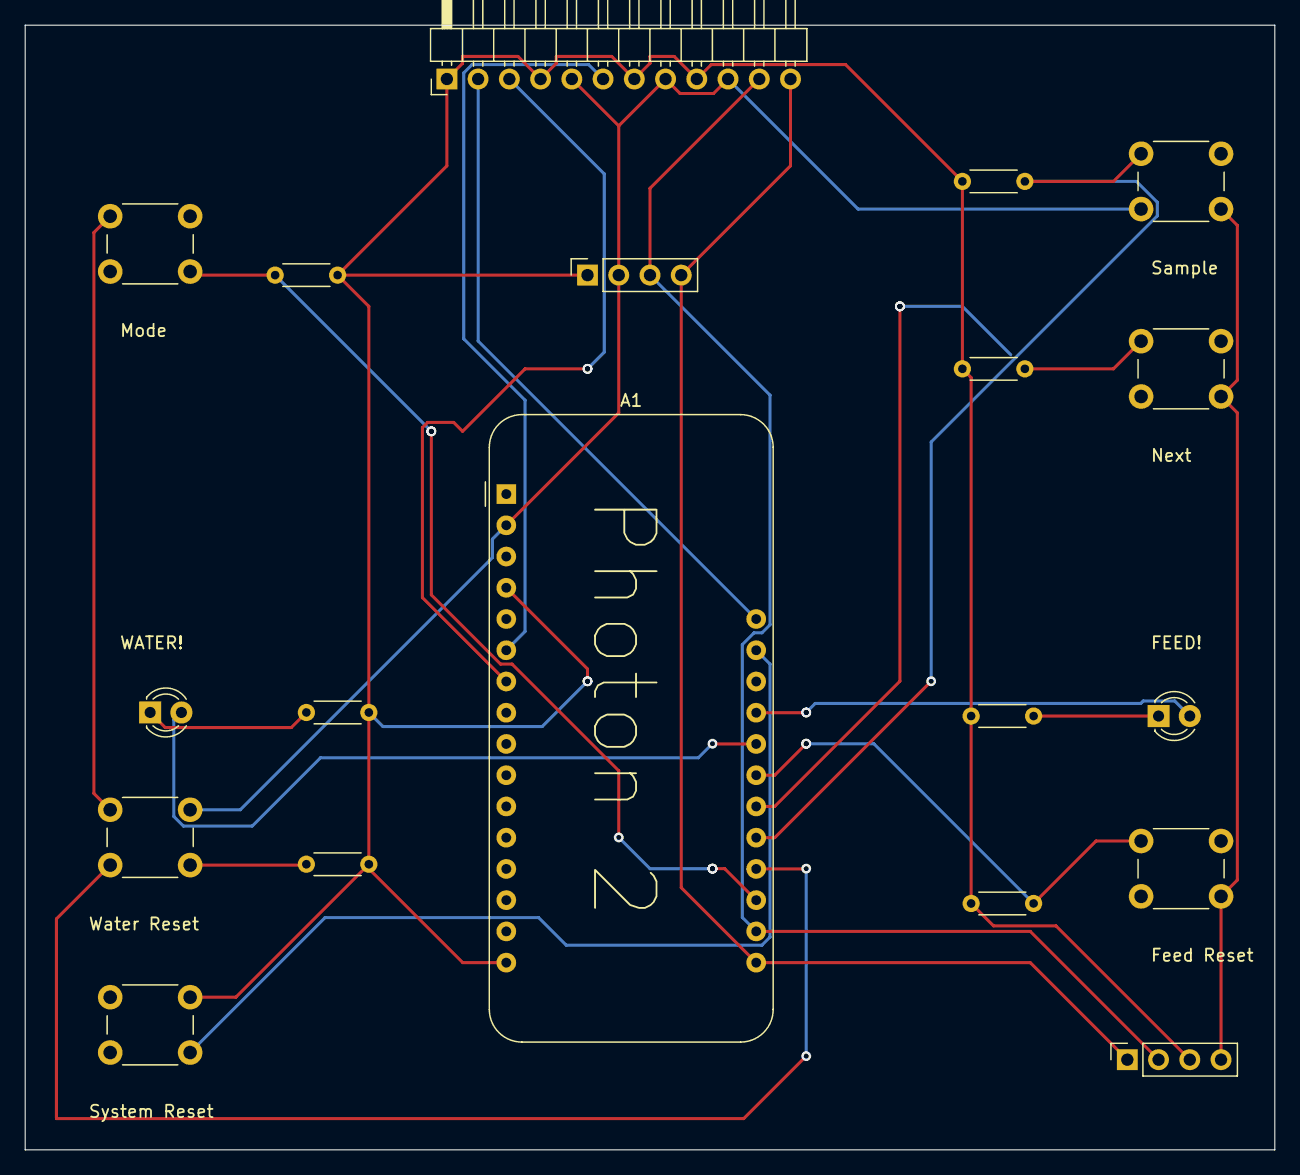
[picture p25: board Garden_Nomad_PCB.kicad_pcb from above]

Board: 2 copper layers, 101.6 x 91.4 mm, 19 parts (0 on the bottom side), 17 nets.

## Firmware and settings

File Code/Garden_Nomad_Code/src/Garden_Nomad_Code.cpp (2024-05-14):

/* 
 * Project Garden Nomad - Smart Garden Monitor
 * Author: Scott Walker
 * Date: 4/26/2024
 */

#include "Particle.h"                                                   // Lines 7-18 Necessary Header Files
#include "IoTClassroom_CNM.h"
#include "Adafruit_I2CDevice.h"
#include "Adafruit_I2CRegister.h"
#include "Adafruit_VEML7700.h"
#include "Adafruit_GFX.h"
#include "Adafruit_SSD1306.h"
#include "Adafruit_BME280.h"
#include "Adafruit_MQTT.h"
#include "Adafruit_MQTT/Adafruit_MQTT_SPARK.h"
#include "Adafruit_MQTT/Adafruit_MQTT.h"
#include "credentials.h"
const int OLED_RESET = -1;                                              // Lines 19-20 Constants for OLED setup
const int OLEDADDRESS = 0x3C;
const int PHPIN = A1;                                                   // Lines 21-29 Defining Pins
const int MOISTUREPIN = A2;
const int MODEBUTTONPIN = D4;
const int SAMPLEBUTTONPIN = D5;
const int FEEDRESETPIN = D6;
const int WATERRESETPIN = D7;
const int NEXTBUTTONPIN = D10;
const int WATERLEDPIN = D3;
const int FEEDLEDPIN = D2;
const int SAMPLEINTERVAL = 20;                                          // Lines 30-31 Constants for PH Sensor
const int ARRAYLENGTH = 40;
const int SLEEPINTERVAL = 300000;                                       // Inactive millis before system sleep
const int BMEADDRESS = 0x76;                                            // Constnat for BME setup
int PHArray[ARRAYLENGTH];                                               // Lines 34-35 Used for PH calculation
int PHArrayIndex;
int modeValue;                                                          // Used to determine what mode the device is in
int displayValue;                                                       // Changes what is displayed in passive mode
int sampleType;                                                         // Changes what sample is being taken in manual sample mode
int waterAlertPCT;                                                      // Threshold for the water alert
int setupModeValue;                                                     // Changes between options in setup menu
int feedDays;                                                           // Threshold for feed alert in days
unsigned long feedAlertMillis;                                          // Threshold for feed alert in millis
unsigned long samplingTime;                                             // Millis for PH sampling timer
unsigned long publishTime;                                              // Millis for data publishing timer
unsigned long displayTime;                                              // Millis for display refresh
unsigned long feedTime;                                                 // Millis for feed alert timer
const float OFFSET = 15.7692;                                           // Lines 47-48 constants for voltage to PH conversion
const float SLOPE = -5.7692;
float PHValue;                                                          // Lines 49-51 PH variables
float voltage;
float lastPH;
bool sleepTimerOn;                                                      // Bools to setup sleep timer, water alert, feed alert
bool waterAlert;
bool feedAlert;
Adafruit_SSD1306 display(OLED_RESET);                                   // Lines 55-58 Defining objects OLED, light sensor, BME, MQTT client
Adafruit_VEML7700 lightSensor;
Adafruit_BME280 bme;
TCPClient TheClient;                                                                 
Adafruit_MQTT_SPARK mqtt(&TheClient, SERVER, SERVERPORT, USERNAME, PASSWORD);       // Lines 59-66 Setup MQTT and feeds to publish to
Adafruit_MQTT_Publish tempPub = Adafruit_MQTT_Publish(&mqtt, "TempFeed");
Adafruit_MQTT_Publish luxPub = Adafruit_MQTT_Publish(&mqtt, "LuxFeed");
Adafruit_MQTT_Publish humPub = Adafruit_MQTT_Publish(&mqtt, "HumFeed");
Adafruit_MQTT_Publish moisturePub = Adafruit_MQTT_Publish(&mqtt, "MoistureFeed");
Adafruit_MQTT_Publish soilPHPub = Adafruit_MQTT_Publish(&mqtt, "SoilPH");
Adafruit_MQTT_Publish waterPHPub = Adafruit_MQTT_Publish(&mqtt, "WaterPH");
Adafruit_MQTT_Publish runoffPub = Adafruit_MQTT_Publish(&mqtt, "RunoffPH");
IoTTimer sleepTimer;                                                    // Lines 67-72 Creating objects - timer and buttons
Button modeButton(MODEBUTTONPIN);
Button sampleButton(SAMPLEBUTTONPIN);
Button feedAlertReset(FEEDRESETPIN);
Button waterAlertReset(WATERRESETPIN);
Button nextButton(NEXTBUTTONPIN);
double averageArray(int *arr, int number);                              // Lines 73-79 Functions for data collection, the various modes, and MQTT communications
void passiveCollection();
void manualSample();
void setupMode();
void sleepULP();
void MQTT_connect();
bool MQTT_ping();

SYSTEM_MODE(AUTOMATIC);

void setup() {

Serial.begin(9600);                                                     // Lines 85-86 Setup Serial monitor
waitFor(Serial.isConnected, 10000);
pinMode(PHPIN, INPUT);                                                  // Lines 87-90 Pinmodes for PH, moisture, LEDs
pinMode(MOISTUREPIN, INPUT);
pinMode(FEEDLEDPIN, OUTPUT);
pinMode(WATERLEDPIN, OUTPUT);
display.begin(SSD1306_SWITCHCAPVCC, OLEDADDRESS);                       // Lines 91-93 Setup OLED display
display.clearDisplay();
display.display();
bme.begin(BMEADDRESS);                                                  // Setup BME
if (!lightSensor.begin()){                                              // Lines 95-100 Setup Light Sensor
  Serial.println("Sensor not found");
  while (1);
}
lightSensor.setGain(VEML7700_GAIN_1_8);
lightSensor.setIntegrationTime(VEML7700_IT_25MS);
PHArrayIndex = 0;                                                       // Lines 101-114 Predefining some variables
samplingTime = millis();
publishTime = millis();
displayTime = millis();
feedTime = millis();
modeValue = 0;
displayValue = 0;
sampleType = 0;
setupModeValue = 0;
lastPH = 0;
feedDays = 7;
waterAlertPCT = 50;
sleepTimerOn = false;
waterAlert = false;

}

void loop() {

MQTT_connect();                                                         // Lines 120-121 Connect to and Ping MQTT Server
MQTT_ping();   
if(sleepTimerOn == false){                                              // Lines 122-125 Starting the sleep timer if the device just woke up
    sleepTimer.startTimer(SLEEPINTERVAL);
    sleepTimerOn = true;
}
if(sleepTimer.isTimerReady() && sleepTimerOn == true){                  // Lines 126-132 Put the device to sleep if the timer is ready. Resets some values so it always wakes up in the same state.
    sleepTimerOn = false;
    modeValue = 0;
    displayValue = 0;
    setupModeValue = 0;
    sleepULP();
}
if(feedAlert == true){                                                  // Lines 133-135 If the feed alert is active, light the LED
    digitalWrite(FEEDLEDPIN, HIGH);
}
if(feedAlert == false){                                                 // Lines 136-138 If the feed alert is inactive, turn off LED
    digitalWrite(FEEDLEDPIN, LOW);
}
if(waterAlert == true){                                                 // Lines 139-141 If the water alert is active, light the LED
    digitalWrite(WATERLEDPIN, HIGH);
}
if(waterAlertReset.isClicked() && waterAlert == false){                 // Lines 142-145 If the water alert is inactive and the reset button is clicked, turn off LED
    digitalWrite(WATERLEDPIN, LOW);
    sleepTimer.startTimer(SLEEPINTERVAL);
}
if(modeButton.isClicked()){                                             // Lines 146-149 If the mode button is clicked, iterate mode value, reset sleep timer
    modeValue++;
    sleepTimer.startTimer(SLEEPINTERVAL);
}
switch(modeValue%3){                                                    // Lines 150-160 Switch case - run different function depending on mode value
    case 0:
        passiveCollection();
        break;
    case 1:
        manualSample();
        break;
    case 2:
        setupMode();
        break;
}

}
bool MQTT_ping() {                                                      // Lines 163-177 Pings the MQTT server periodically, obtained in clas, not written by me
  static unsigned int last;
  bool pingStatus;

  if ((millis()-last)>120000) {
      Serial.printf("Pinging MQTT \n");
      pingStatus = mqtt.ping();
      if(!pingStatus) {
        Serial.printf("Disconnecting \n");
        mqtt.disconnect();
      }
      last = millis();
  }
  return pingStatus;
}
void MQTT_connect() {                                                   // Lines 178-195 Connects to the MQTT server if not already connected, obtained in class, not written by me
  int8_t ret;
 
  // Return if already connected.
  if (mqtt.connected()) {
    return;
  }
 
  Serial.print("Connecting to MQTT... ");
 
  while ((ret = mqtt.connect()) != 0) { // connect will return 0 for connected
       Serial.printf("Error Code %s\n",mqtt.connectErrorString(ret));
       Serial.printf("Retrying MQTT connection in 5 seconds...\n");
       mqtt.disconnect();
       delay(5000);  // wait 5 seconds and try again
  }
  Serial.printf("MQTT Connected!\n");
}
double averageArray(int *arr, int number){                              // Lines 196-239 Function to collect voltage data from the PH sensor, then fill and average an array, found online and edited by me
  int i;
  int max, min;
  double avg;
  long amount = 0;
  if(number <= 0){
    Serial.printf("Error: Divide by Zero\n");
    return 0;
  }
  if(number < 5){
    for(i =0; i < number; i++){
      amount += arr[i];
    }
    avg = amount/number;
    return avg;
  }
  else{
    if(arr[0] < arr[1]){
      min = arr[0];
      max = arr[1];
    }
    else{
      min = arr[1];
      max = arr[0];
    }
    for(i = 2; i < number; i++){
      if(arr[i] < min){
        amount += min;
        min = arr[i];
      }
      else{
        if(arr[i] > max){
          amount += max;
          max = arr[i];
        }
        else{
          amount += arr[i];
        }
      }
    }
    avg = (double)amount/(number - 2);
  }
  return avg;
}

void passiveCollection(){                                               // Lines 241-345 Function for passive data collection mode
    int luxValue;                                                           // 242-247 Defining variables
    int moisture;
    float tempC;
    float tempF;
    float humidRH;
    float moisturePCT;
    luxValue = lightSensor.readLux();                                       // 248-253 Obtaining data and converting to relevant units
    tempC = bme.readTemperature();
    humidRH = bme.readHumidity();
    tempF = (9.0/5.0)*tempC + 32;
    moisture = analogRead(MOISTUREPIN);
    moisturePCT = (-(100.0/2000.0)*moisture) + 155.0;
    if(moisturePCT < waterAlertPCT){                                        // 254-259 Turns water alert on or off based on soil moisture
        waterAlert = true;
    }
    if(moisturePCT > waterAlertPCT){
        waterAlert = false;
    }
    if(millis() - publishTime > 5000){                                      // 260-266 Publishes data to cloud every five seconds (if awake and in this mode)
        tempPub.publish(tempF);
        luxPub.publish(luxValue);
        humPub.publish(humidRH);
        moisturePub.publish(moisturePCT);
        waterPHPub.publish(lastPH);
        publishTime = millis();
    }
    if(nextButton.isClicked()){                                             // 267-269 Iterates display value and resets sleep timer when Next button is clicked
        displayValue++;
        sleepTimer.startTimer(SLEEPINTERVAL);
    }
    if(millis() - displayTime > 500){                                       // 270-325 Refreshes display every 500 millis, displays different values based on display value
        if(displayValue%6 == 0){
            display.clearDisplay();
            display.setTextSize(1);
            display.setTextColor(WHITE);
            display.setCursor(0, 10);
            display.printf("Lux: %i\nMoisture: %0.0f%%\nTemp: %0.2fF\nHum: %0.2f\nLast PH: %0.2f\n", luxValue, moisturePCT, tempF, humidRH, lastPH);
            display.display();
            displayTime = millis();
        }
        if(displayValue%6 == 1){
            display.clearDisplay();
            display.setTextSize(2);
            display.setTextColor(WHITE);
            display.setCursor(0, 10);
            display.printf("Lux:\n%i\n", luxValue);
            display.display();
            displayTime = millis();
        }
        if(displayValue%6 == 2){
            display.clearDisplay();
            display.setTextSize(2);
            display.setTextColor(WHITE);
            display.setCursor(0, 10);
            display.printf("Moisture:\n%0.0f%%\n", moisturePCT);
            display.display();
            displayTime = millis();
        }
        if(displayValue%6 == 3){
            display.clearDisplay();
            display.setTextSize(2);
            display.setTextColor(WHITE);
            display.setCursor(0, 10);
            display.printf("Temp:\n%0.2fF\n", tempF);
            display.display();
            displayTime = millis();
        }
        if(displayValue%6 == 4){
            display.clearDisplay();
            display.setTextSize(2);
            display.setTextColor(WHITE);
            display.setCursor(0, 10);
            display.printf("Hum:\n%0.2f\n", humidRH);
            display.display();
            displayTime = millis();
        }
        if(displayValue%6 == 5){
            display.clearDisplay();
            display.setTextSize(2);
            display.setTextColor(WHITE);
            display.setCursor(0, 10);
            display.printf("Last PH:\n%0.2f\n", lastPH);
            display.display();
            displayTime = millis();
        }
    }
    feedAlertMillis = feedDays * 24 * 60 * 60 * 1000;                       // Converts feed alert days into millis
    if(millis() - feedTime > feedAlertMillis){                              // Lines 327-329 turns on feed alert if enough time has passed
        feedAlert = true;
    }
    if(feedAlertReset.isClicked() & feedAlert == true){                     // Lines 330-334 turns off feed alert if button is pressed, restarts feed timer and sleep timer 
        feedAlert = false;
        feedTime = millis();
        sleepTimer.startTimer(SLEEPINTERVAL);
    }
}

void manualSample(){                                                    // Lines 338-405 Function for manual data collection mode                                            
    float soilSample;                                                       // 339-341 Defining Variables
    float waterSample;
    float runoffSample;
    if(millis() - samplingTime > SAMPLEINTERVAL){                           // 342-350 Populating an array with PH voltage values, averaging them, converting average to PH
        PHArray[PHArrayIndex++] = analogRead(PHPIN);
        if(PHArrayIndex == ARRAYLENGTH){
            PHArrayIndex = 0;
        }
        voltage = averageArray(PHArray, ARRAYLENGTH) * 3.3/4096;
        PHValue = SLOPE * voltage + OFFSET;
        samplingTime = millis();
    }
    if(millis() - displayTime > 500){                                       // 351-367 Refreshing the display with relevant data every 500 millis
        display.clearDisplay();
        display.setTextSize(2);
        display.setTextColor(WHITE);
        display.setCursor(0, 10);
        if(sampleType%3 == 0){
            display.printf("Soil PH:\n%0.2f\n", PHValue);                       // Changes sample type displayed depending on which one you're sampling
        }
        if(sampleType%3 == 1){
            display.printf("Water PH:\n%0.2f\n", PHValue);
        }
        if(sampleType%3 == 2){
            display.printf("Runoff PH:\n%0.2f\n", PHValue);
        }
        display.display();
        displayTime = millis();
    }
    if(nextButton.isClicked()){                                             // 368-386 Changes active sample type and displays it on press of Next button, also resetting sleep timer
        sampleType++;
        sleepTimer.startTimer(SLEEPINTERVAL);
        display.clearDisplay();
        display.setTextSize(2);
        display.setTextColor(WHITE);
        display.setCursor(0, 10);
        if(sampleType%3 == 0){
            display.printf("Soil PH:\n%0.2f\n", PHValue);
        }
        if(sampleType%3 == 1){
            display.printf("Water PH:\n%0.2f\n", PHValue);
        }
        if(sampleType%3 == 2){
            display.printf("Runoff PH:\n%0.2f\n", PHValue);
        }
        display.display();
        displayTime = millis();
    }
    if(sampleButton.isClicked()){                                           // Saves the value of the active sample and sends it to the cloud when Sample button is pressed, also resetting sleep timer
        if(sampleType%3 == 0){
            soilSample = PHValue;
            lastPH = PHValue;
            soilPHPub.publish(soilSample);
        }
        if(sampleType%3 == 1){
            waterSample = PHValue;
            lastPH = PHValue;
            waterPHPub.publish(waterSample);
        }
        if(sampleType%3 == 2){
            runoffSample = PHValue;
            lastPH = PHValue;
            runoffPub.publish(runoffSample);
        }
        sleepTimer.startTimer(SLEEPINTERVAL);
    }
}
void setupMode(){                                                       // Lines 406-459 Function for setup mode
    if(nextButton.isClicked()){                                             // 407-410 Next button cycles through setup modes, resets sleep timer
        setupModeValue++;
        sleepTimer.startTimer(SLEEPINTERVAL);
    }
    if(setupModeValue%2 == 0){                                              // 411-434 Displays what setup mode you're in, changes the water alert threshold if sample button is pressed
        if(millis() - displayTime > 500){
            display.clearDisplay();
            display.setTextSize(2);
            display.setTextColor(WHITE);
            display.setCursor(0, 10);
            display.printf("Water Threshold:\n%i%%\n", waterAlertPCT);
            display.display();
            displayTime = millis();
        }
        if(sampleButton.isClicked()){
            waterAlertPCT = waterAlertPCT + 5;
            if(waterAlertPCT > 100){
                waterAlertPCT = 0;
            }
            display.clearDisplay();
            display.setTextSize(2);
            display.setTextColor(WHITE);
            display.setCursor(0, 10);
            display.printf("Water Threshold:\n%i%%\n", waterAlertPCT);
            display.display();
            displayTime = millis();
        }
    }
    if(setupModeValue%2 == 1){                                              // 435-458 Displays what setup mode you're in, changes the feed interval when sample button is pressed
        if(millis() - displayTime > 500){
            display.clearDisplay();
            display.setTextSize(2);
            display.setTextColor(WHITE);
            display.setCursor(0, 10);
            display.printf("Feeding Interval:\n%i days\n", feedDays);
            display.display();
            displayTime = millis();
        }
        if(sampleButton.isClicked()){
            feedDays++;
            if(feedDays > 14){
                feedDays = 1;
            }
            display.clearDisplay();
            display.setTextSize(2);
            display.setTextColor(WHITE);
            display.setCursor(0, 10);
            display.printf("Feeding Interval:\n%i days\n", feedDays);
            display.display();
            displayTime = millis();
        }
    }
}
void sleepULP(){                                                        // Lines 460-470 Function for sleep mode, wakes up on button press or after duration
    SystemSleepConfiguration config;
    config.mode(SystemSleepMode::ULTRA_LOW_POWER).gpio(D4, RISING).gpio(D5, RISING).gpio(D6, RISING).gpio(D7, RISING).gpio(D10, RISING).duration(720000);
    SystemSleepResult result = System.sleep(config);
    if(result.wakeupReason() == SystemSleepWakeupReason::BY_GPIO){
        Serial.printf("Awakened by GPIO %i\n", result.wakeupPin());
    }
    if(result.wakeupReason() == SystemSleepWakeupReason::BY_RTC){
        Serial.printf("Awakened by RTC\n");
    }
}

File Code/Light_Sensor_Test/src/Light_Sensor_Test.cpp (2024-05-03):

/* 
 * Project Light Sensor
 * Author: Scott Walker
 * Date: 4/19/2024
 */

#include "Particle.h"
#include "Adafruit_GFX.h"
#include "Adafruit_SSD1306.h"   
#include "Adafruit_VEML7700.h"
int lastTime;
uint16_t luxValue;
const int OLED_RESET = -1;
const int OLEDADDRESS = 0x3C;
Adafruit_SSD1306 display(OLED_RESET);
Adafruit_VEML7700 veml;

SYSTEM_MODE(AUTOMATIC);

void setup() {

Serial.begin(9600);
waitFor(Serial.isConnected, 10000);
display.begin(SSD1306_SWITCHCAPVCC, OLEDADDRESS);
display.clearDisplay();
display.display();
lastTime = millis();
if (!veml.begin()){
  Serial.println("Sensor not found");
  while (1);
}
Serial.println("Sensor found");
//Wire.begin();
//Wire.beginTransmission(0x10);
//Wire.write(0x00);
//Wire.write(0x1300);
//Wire.endTransmission(true);

}

void loop() {

if(millis() - lastTime > 1000){
  //Wire.begin();
  //Wire.beginTransmission(0x10);
  //Wire.write(0x05);
  //Wire.endTransmission(false);
  //Wire.requestFrom(0x10, 1, true);
  //luxValue = Wire.read();
  Serial.printf("Lux value: %0.0f\n", veml.readLux());
  lastTime = millis();
  display.clearDisplay();
  display.setTextSize(2);
  display.setTextColor(WHITE);
  display.setCursor(0, 0);
  display.printf("Lux value %0.0f\n", veml.readLux());
  display.display();
}

}

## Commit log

2024-04-19 Added flowcharts
2024-04-19 PH Calibrated and working
2024-04-19 Calibrating/testing light sensor
2024-04-19 Designed initial body/case
    [Main_Body_Case.SLDPRT, Main_Body_Case.STL]
2024-04-19 Organizing files and folders
    [Main_Body_Case.SLDPRT, Main_Body_Case.STL]
2024-04-26 Fritzing, Hinge Design, PH Probe Housing Design
    [Garden_Nomad_Fritzing.fzz, Hinge_Assembly.SLDASM, Hinge_Pin.SLDPRT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]
2024-04-26 Fritzing schematic
    [Garden_Nomad_Fritzing.fzz]
2024-05-02 Wrote most of the code, needs testing
    [Garden_Nomad_Fritzing.fzz, Hinge_Assembly.SLDASM, Hinge_Side_1.SLDPRT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]
2024-05-03 Most of the code working, light sensor library may be causing problems
    [PH_Probe_Housing.SLDPRT, PH_Probe_Housing.STL]
2024-05-03 Solved light sensor, code working, just need MQTT, sleep mode
    [Garden_Nomad_Code.cpp, Light_Sensor_Test.cpp]
2024-05-10 Code is working, more 3D designs, Laser cutter design
    [Front_Door.SLDPRT, Front_Door.STL, Garden_Nomad_PCB.kicad_pcb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]
2024-05-14 Commented code, lowered sleep duration (for now), added PDFs of all notes, finished PCB
    [Front_Door.SLDPRT, Front_Door.STL, Garden_Nomad_Fritzing.fzz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]
2024-05-16 ReadMe updated
    [Hinge_Assembly.STL]
